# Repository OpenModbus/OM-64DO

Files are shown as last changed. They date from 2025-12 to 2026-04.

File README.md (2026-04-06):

# Open Modbus OM-64DO









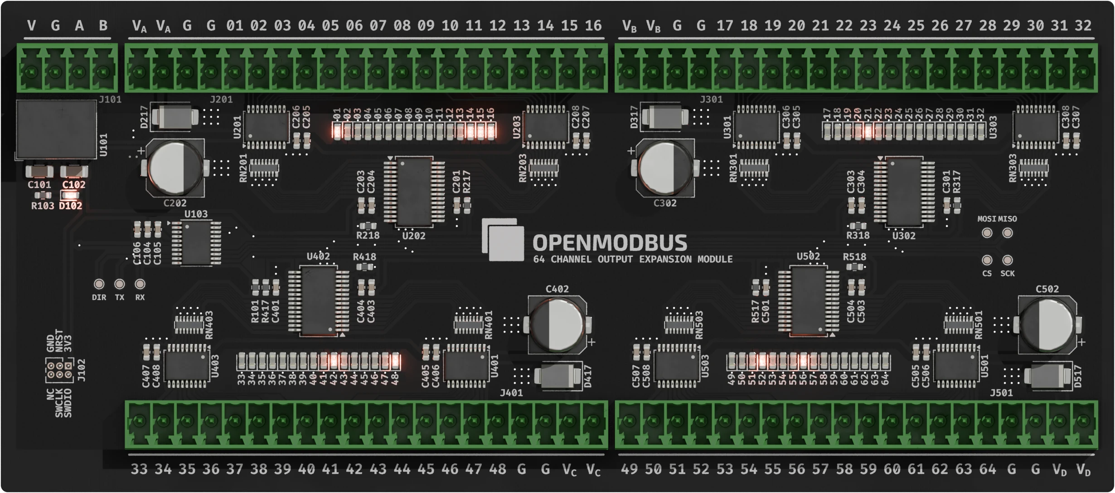
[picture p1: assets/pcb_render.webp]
PCB Render


A compact industrial-grade **64-channel Modbus RTU output module** featuring low-side drivers, per-channel LEDs, wide input voltage, DIN-rail support, and full configuration via Modbus holding registers. Designed for automation, distributed I/O, and custom control applications.

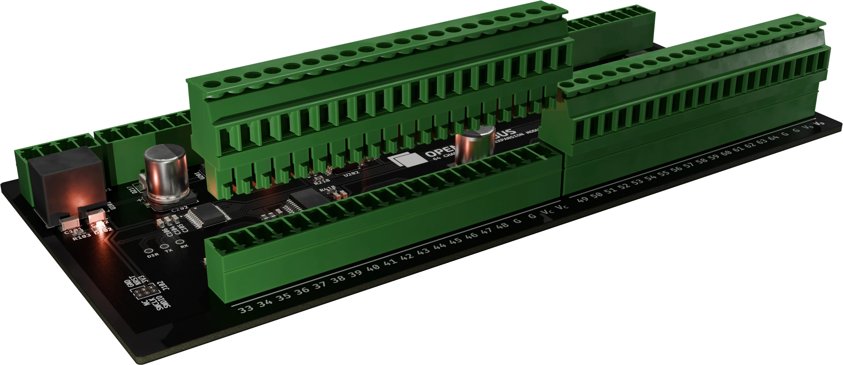
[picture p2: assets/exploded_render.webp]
Exploded PCB Render


## 1. Product Overview

The **Open Modbus OM-64DO** is a 64-channel low-side output expansion module intended for industrial automation, machine control, and distributed I/O networks using **Modbus RTU** over RS-485.  
It switches DC loads such as solenoids, relays, indicator lamps, locks, and alarms up to **48 VDC**.

The module combines an **STM32G031** microcontroller, four **MCP23S17 SPI expanders**, and eight **TBD62083 Darlington driver arrays**.  
This architecture enables reliable, flexible, and scalable output control with built-in protection and per-channel LED indication.

### 📦 Hardware Files

The full schematic and BOM are available at:

- Schematic → [https://github.com/OpenModbus/OM-64DO/blob/main/assets/schematics.pdf](https://github.com/OpenModbus/OM-64DO/blob/main/assets/schematics.pdf)
- BOM → [https://github.com/OpenModbus/OM-64DO/blob/main/assets/bom.csv](https://github.com/OpenModbus/OM-64DO/blob/main/assets/bom.csv)

Check the latest release for more!

## 2. Key Features

- 64 open-collector low-side outputs  
- Up to **500 mA per output**, **2 A max** per driver package  
- **5–48 VDC** recommended load voltage (50 V absolute maximum)  
- Wide supply input: **7–28 VDC**  
- RS-485 Modbus RTU communication (THVD1450 transceiver)  
- Fully configurable serial parameters  
- Per-channel LED indicators  
- DEGSON 15EDG pluggable screw terminals
- DIN-rail mount using **UM72S profile**  
- Compact PCB (163 × 72 mm)

## 3. Applications

Ideal for:

- PLC expansion  
- Building automation  
- Access control  
- Alarm and signaling systems  
- Relay switching  
- Industrial prototyping  

## 4. Hardware Architecture

### Microcontroller  

The STM32G031F8P6 MCU handles Modbus RTU processing, configuration storage, SPI communication, and output refresh logic.

### I/O Expanders  

Four MCP23S17 SPI-based expanders provide the 64 output control signals in groups of 16.

### Output Drivers  

The TBD62083 Darlington arrays switch the actual loads.  
Their key characteristics include:

- 8 channels per IC  
- 500 mA per channel  
- 2 A total per IC  
- Integrated flyback diodes  
- LED indication per channel  

### RS-485 Communication  

A robust THVD1450 transceiver provides differential RS-485 communication with:

- Fail-safe features  
- High ESD immunity  
- Suitable for long cable runs  

### Power  

The board accepts **7–28 VDC** and includes a high-efficiency **R-78E3.3-0.5** regulator for its 3.3 V logic domain.

## 5. Electrical Specifications

### Supply  

- **7–28 VDC** input  
- Internal regulated **3.3 V logic**  
- Low power MCU operation  

### Outputs  

- 64 open-collector low-side channels  
- 5–48 VDC recommended load  
- 50 VDC absolute maximum  
- 500 mA max per output  
- 2 A max per driver IC  
- Built-in flyback protection  
- LED indicator on each output  

### Communication  

- RS-485, 2-wire  
- Modbus RTU protocol  
- Default settings: **9600 baud, 8N1, address 1**  
- All communication parameters can be reconfigured via holding registers  

## 6. Mechanical Information

- PCB: **163 × 72 mm**  
- DIN-rail enclosure compatibility: **UM72S profile**  
- DEGSON 15EDG pluggable screw terminals  
- Mounting suitable for industrial control cabinets  

## 7. Functional Overview

Each output activates when its Modbus coil value is **1**, causing the driver to sink current to ground.  
When the coil value is **0**, the channel turns off, leaving the load unpowered.

A dedicated LED mirrors the state of each output channel.

## 8. Modbus Interface

### Supported Function Codes

- *0x01* — Read Coils  
- *0x05* — Write Single Coil  
- *0x0F* — Write Multiple Coils  
- *0x03* — Read Holding Registers  
- *0x06* — Write Single Register  
- *0x10* — Write Multiple Registers  

### Coils (Outputs 1–64)

Coils map directly to output channels.  
Addressing begins at **0x00**.

| Coil Address (Hex) | Function |
|---|---|
| 0  (**0x00**) | OUTPUT 1 |
| 1  (**0x01**) | OUTPUT 2 |
| 2  (**0x02**) | OUTPUT 3 |
| 3  (**0x03**) | OUTPUT 4 |
| 4  (**0x04**) | OUTPUT 5 |
| … | … |
| 63 (**0x3F**) | OUTPUT 64 |

### Holding Registers

Configuration registers start at **0x00** and are stored in non-volatile memory.

| Register Address (Hex) | Name | Description | Allowed Values | Default |
|---|---|---|---|---|
| 0 (**0x00**) | Slave Address  | Modbus device ID | 1–247 | 1 |
| 1 (**0x01**) | Baud Rate Code | Serial speed selector: **0=1200**, **1=2400**, **2=4800**, **3=9600**, **4=19200**, **5=38400**, **6=57600**, **7=115200**, **8=230400**, **9=460800**, **10=921600** | 0–10 | 3 |
| 2 (**0x02**) | Parity | Communication parity | 0=None, 1=Even, 2=Odd | 0 |
| 3 (**0x03**) | Data Bits | Serial data width | 5–9 (typ. 8) | 8 |
| 4 (**0x04**) | Stop Bits | Serial stop bits | 1–2 | 1 |

### Example Modbus Commands

Below are typical Modbus RTU frames for controlling and configuring the OM-64DO.

#### Turn ON Output 1  

Function: Write Single Coil (0x05)  
Coil address: `0x0000`  
Value: ON → `0xFF00`  
**Frame:** `01 05 00 00 FF 00 8C 3A`

#### Turn ON Outputs 5–12  

Function: Write Multiple Coils (0x0F)  
Start address: `0x0004`  
Quantity: `0x0008` (8 coils)  
Data: `FF` (all eight bits ON)  
**Frame:** `01 0F 00 04 00 08 01 FF 4F 15`

#### Turn ON All Outputs (1–64)

Function: Write Multiple Coils (0x0F)  
Start address: `0x0000`  
Quantity: `0x0040` (64 coils)  
Data: `FF FF FF FF FF FF FF FF`  
**Frame:** `01 0F 00 00 00 40 08 FF FF FF FF FF FF FF FF AA 20`

#### Turn OFF All Outputs

Function: Write Multiple Coils (0x0F)  
Start address: `0x0000`  
Quantity: `0x0040`  
Data: `00 00 00 00 00 00 00 00`  
**Frame:** `01 0F 00 00 00 40 08 00 00 00 00 00 00 00 00 EB A4`

#### Read All Outputs

Function: Read Coils (0x01)  
Start address: `0x0000`  
Quantity: `0x0040`  
**Frame:** `01 01 00 00 00 40 3D FA`

#### Set Device Address

Function: Write Single Register (0x06)  
Register: `0x0000` (Slave Address)  
Value: `0x0005`  
**Frame:** `01 06 00 00 00 05 49 C9`

#### Set Baud Rate

Function: Write Single Register (0x06)  
Register: `0x0001` (Baud Rate Code)  
Value: `0x0007` → 115200 baud  
**Frame:** `01 06 00 01 00 07 99 C8`

## 9. Wiring  

The **OM-64DO** uses low-side (open-collector) switching.
That means the module connects the load to ground when ON, and the load must be powered from your external power supply.

The 64 outputs are grouped into four banks of 16 (Bank A–D).
This allows one board to drive devices powered from different voltages simultaneously.

**Examples**:

- Bank A → 12 V devices
- Bank B → 24 V relays
- Bank C → 48 V solenoids
- Bank D → 5 V indicators

### Low-Side Output Principle

Each output contains a protected Darlington transistor that sinks current:

```text
Load +V  ─────── Load ─────── OUTx (SINK)
                                    │
                                    └── GND (OM-64DO)
```

### Recommended Wiring Steps

- Connect the load voltage (5–48 VDC) to the Vx terminal of the bank.
- Connect the output pin (OUTx) to the negative side of the load.
- Tie power supply GND to OM-64DO GND.
- Ensure the supply can support the total current of that bank.

**⚠️ Important Grounding Requirement**:
All load power supplies must share **a common ground** with the OM-64DO.
This is required for the low-side drivers and internal logic to reference the same electrical 0 V.

### Wiring Example

The example below shows how to drive 24 V and 12 V relays at the same time using separate banks.

- Bank A (VA) → 24 V relays
- Bank B (VB) → 12 V relays
- Both supplies share a common ground
- Loads return their negative side to the selected OUTx channel

<picture>
  <source media="(prefers-color-scheme: dark)" srcset="./assets/wiring_example_dark.png">
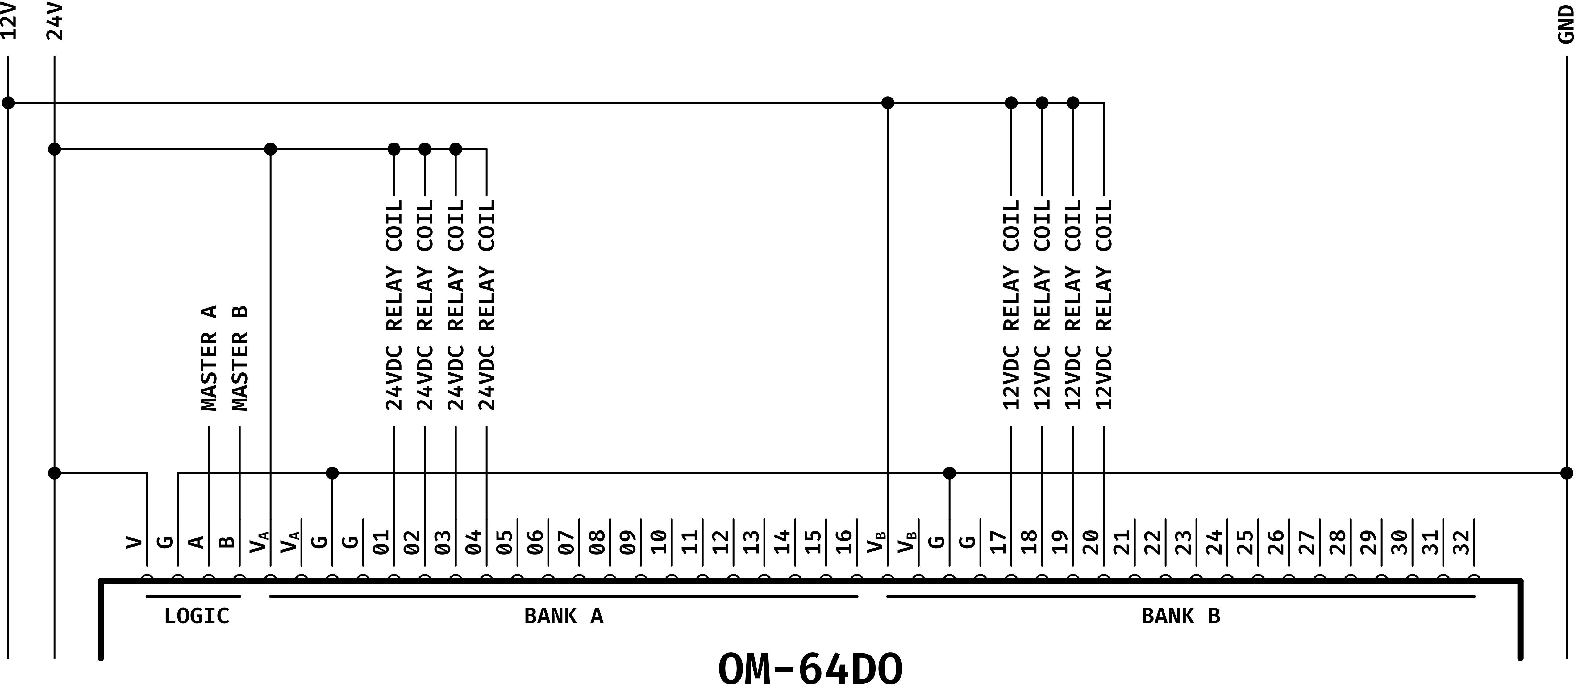
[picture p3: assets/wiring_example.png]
Wiring example
  
</picture>

This wiring approach can be extended to all four banks, each with its own voltage.

## 10. Safety Notes

- Do not exceed **50 VDC** load voltage  
- Ensure load currents stay within limits  
- For inductive loads, external suppression can further improve reliability  
- Maintain proper RS-485 termination and shielding  

## 11. Contact & Support  

For questions, feedback, or technical assistance regarding the Open Modbus OM-64DO, the following support channels are available:

### 📧 Email Support

For general inquiries, firmware questions, or troubleshooting:
[contact@sszczep.dev](mailto:contact@sszczep.dev)

### 🛠 GitHub Repository

Issue tracker, source code, hardware design files, and community contributions:
[https://github.com/OpenModbus/OM-64DO](https://github.com/OpenModbus/OM-64DO)

### 💬 Open Modbus Discussions

Share projects, ask for help, or suggest features:
[https://github.com/orgs/OpenModbus/discussions](https://github.com/orgs/OpenModbus/discussions)

### 📝 Bug Reports & Feature Requests

Submit issues directly via GitHub Issues:
[https://github.com/OpenModbus/OM-64DO/issues](https://github.com/OpenModbus/OM-64DO/issues)

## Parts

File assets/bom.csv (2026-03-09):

Reference | Value | Datasheet | Opis | Qty | # | Manufacturer | Part Number | Mouser# | LCSC#
U202,U302,U402,U502 | MCP23S17T-E/SS | http://ww1.microchip.com/downloads/en/DeviceDoc/20001952C.pdf | 16-bit I/O expander, SPI, interrupts, w pull-ups, SSOP-28 | 4 | 1 | Microchip | MCP23S17T-E/SS | 579-MCP23S17T-E/SS | C128577
U101 | R-78E3.3-0.5 | https://recom-power.com/pdf/Innoline/R-78E-0.5.pdf | 0.5A Step-Down DC/DC-Regulator, 6-28V input, 3.3V fixed Output Voltage, LM78xx replacement, -40°C to +85°C, SIP3 | 1 | 2 | RECOM | R-78E3.3-0.5 | 919-R-78E3.3-0.5 | C18212316
U201,U203,U301,U303,U401,U403,U501,U503 | TBD62083AFNG | https://toshiba.semicon-storage.com/info/datasheet_en_20160511.pdf?did=29893 | Gate Drivers DMOS Transistor Array 8-CH, 50V/0.5A | 8 | 3 | Toshiba | TBD62083AFNG,EL | 757-TBD62083AFNGEL | C163229
F101 | 0.5A | https://www.littelfuse.com/assetdocs/littelfuse_fuse_466_datasheet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 | Fuse, small symbol | 1 | 4 | Littelfuse | 0466.500NR | 576-0466.500NR | C151133
D217,D317,D417,D517 | SMBJ45A | https://www.littelfuse.com/assetdocs/tvs-diodes-smbj-series-datasheet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 | ESD Protection Diodes / TVS Diodes TVS 500W 50V | 4 | 5 | Littelfuse | SMBJ45A | 576-SMBJ45A | C720171
D104 | SMAJ28A | https://www.littelfuse.com/media?itemid=75e32973-b177-4ee3-a0ff-cedaf1abdb93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 | 400W unidirectional Transient Voltage Suppressor, 28.0Vr, SMA(DO-214AC) | 1 | 6 | Littelfuse | SMAJ28A | 576-SMAJ28A | C148227
D101 | SM712-02HTG | https://www.littelfuse.com/~/media/electronics/datasheets/tvs_diode_arrays/littelfuse_tvs_diode_array_sm712_datasheet.pdf.pdf | 7V/12V, 600W Asymmetrical TVS Diode Array, SOT-23 | 1 | 7 | Littelfuse | SM712-02HTG | 576-SM712-02HTG | C172881
D103 | CD123D-B140LR | https://www.mouser.com/catalog/specsheets/bourns_CD123D-B1xR.pdf | Schottky diode, small symbol | 1 | 8 | Bourns | CD123D-B140LR | 652-CD123D-B140LR | C6877135
U103 | STM32G031F8P6 | https://www.st.com/resource/en/datasheet/stm32g031f8.pdf | STMicroelectronics Arm Cortex-M0+ MCU, 64KB flash, 8KB RAM, 64 MHz, 1.7-3.6V, 18 GPIO, TSSOP20 | 1 | 9 | STMicroelectronics | STM32G031F8P6 | 511-STM32G031F8P6 | C529334
U102 | THVD1450DRBR | https://www.ti.com/lit/ds/symlink/thvd1450.pdf | 3.3-V to 5-V RS-485 transceiver with ±18-kV IEC ESD protection, VSON-8 | 1 | 10 | Texas Instruments | THVD1450DRBR | 595-THVD1450DRBR | C1850226
C101,C102 | 10u | ~ | 10 uF 50 VDC 10% 1206 X5R AEC-Q200 | 2 | 11 | Murata | GRT31CR61H106KE01L | 81-GRT31CR61H106KE1L | C417124
C103,C105,C106,C201,C204,C206,C208,C301,C304,C306,C308,C401,C404,C406,C408,C501,C504,C506,C508 | 0.1u | ~ | 0.1 uF 50 VDC 10% 0603 X7R AEC-Q200 | 19 | 12 | Murata | GCJ188R71H104KA12D | 81-GCJ188R71H104KA2D | C161115
C104,C203,C303,C403,C503 | 2.2u | ~ | 2.2 uF 50 VDC 10% 0603 X5R AEC-Q200 | 5 | 13 | Murata | GRT188R61H225KE13D | 81-GRT188R61H225KE3D | C668370
C202,C302,C402,C502 | 100u | ~ | Aluminum Electrolytic Capacitors - SMD 100UF 63V 20% | 4 | 14 | Nichicon | UCM1J101MNL1GS | 647-UCM1J101MNL1GS | C445456
C205,C207,C305,C307,C405,C407,C505,C507 | 1u | ~ | 1 uF 50 VDC 10% 0603 X5R AEC-Q200 | 8 | 15 | Murata | GRT188R61H105KE13D | 81-GRT188R61H105KE3D | C126631
D102,D201,D202,D203,D204,D205,D206,D207,D208,D209,D210,D211,D212,D213,D214,D215,D216,D301,D302,D303,D304,D305,D306,D307,D308,D309,D310,D311,D312,D313,D314,D315,D316,D401,D402,D403,D404,D405,D406,D407,D408,D409,D410,D411,D412,D413,D414,D415,D416,D501,D502,D503,D504,D505,D506,D507,D508,D509,D510,D511,D512,D513,D514,D515,D516 | RED | ~ | Single Color LEDs Red Clear 621nm | 65 | 16 | LITEON | LTST-C190EKT | 859-LTST-C190EKT | C364560
J101 | 15EDGVC-3.5-4P | ~ | Generic connector, single row, 01x04, script generated (kicad-library-utils/schlib/autogen/connector/) | 1 | 17 | DEGSON | 10030000681 |  | C22380434
J102 | 02x03 1.27 | ~ | Generic connector, double row, 02x03, odd/even pin numbering scheme (row 1 odd numbers, row 2 even numbers), script generated (kicad-library-utils/schlib/autogen/connector/) | 1 | 18
J201,J301,J401,J501 | 15EDGVC-3.5-20P | ~ | Fixed Terminal Blocks | 4 | 19 | DEGSON | 10030000695 |  | C5188336
R101,R102,R217,R317,R417,R517 | 10K | ~ | SMD 0603 10KOhm 1% 1/8W AEC-Q200 | 6 | 20 | Panasonic | ERJ-H3EF1002V | 667-ERJ-H3EF1002V | C4297913
R103 | 470 | ~ | SMD 0603 470Ohm 5% 1/4W AEC-Q200 | 1 | 21 | Panasonic | ERJ-UP3J471V | 667-ERJ-UP3J471V | C491199
R201,R202,R203,R204,R205,R206,R207,R208,R209,R210,R211,R212,R213,R214,R215,R216,R301,R302,R303,R304,R305,R306,R307,R308,R309,R310,R311,R312,R313,R314,R315,R316,R401,R402,R403,R404,R405,R406,R407,R408,R409,R410,R411,R412,R413,R414,R415,R416,R501,R502,R503,R504,R505,R506,R507,R508,R509,R510,R511,R512,R513,R514,R515,R516 | 3K3 | ~ | SMD 0603 3K3Ohm 5% 1/4W AEC-Q200 | 64 | 22 | Panasonic | ERJ-UP3J332V | 667-ERJ-UP3J332V | C491202
R218,R318,R418,R518 | 33 | ~ | SMD 0603 33Ohm 1% 1/8W AEC-Q200 | 4 | 23 | Panasonic | ERJ-H3EF33R0V | 667-ERJ-H3EF33R0V | C4313361
RN201,RN203,RN301,RN303,RN401,RN403,RN501,RN503 | 47R | ~ | Resistor Array Convex 8x0602 47Ohm 5% AEC-Q200 | 8 | 24 | Panasonic | EXB-2HV470JV | 667-EXB-2HV470JV | C713462
RN202,RN204,RN302,RN304,RN402,RN404,RN502,RN504 | 100K | ~ | Resistor Array Convex 8x0602 100KOhm 5% AEC-Q200 | 8 | 25 | Panasonic | EXB-2HV104JV | 667-EXB-2HV104JV | C713455

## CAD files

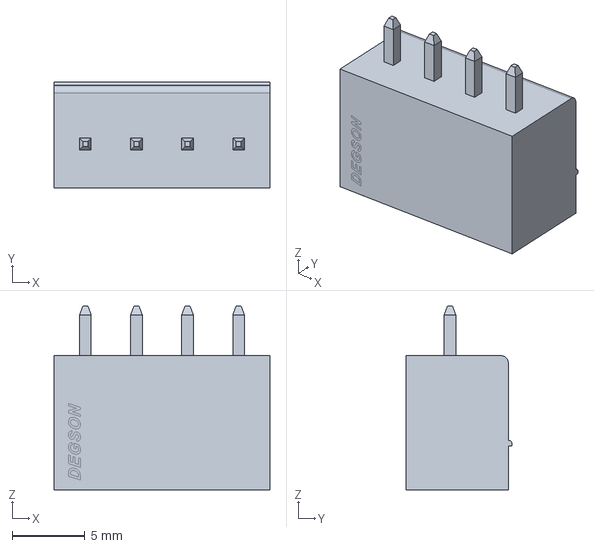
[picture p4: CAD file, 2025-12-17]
kicad/Project_Models/15EDGVC-3.5-04P-14-00A&Z(H).stp
14.8 x 7.24 x 12.6 mm

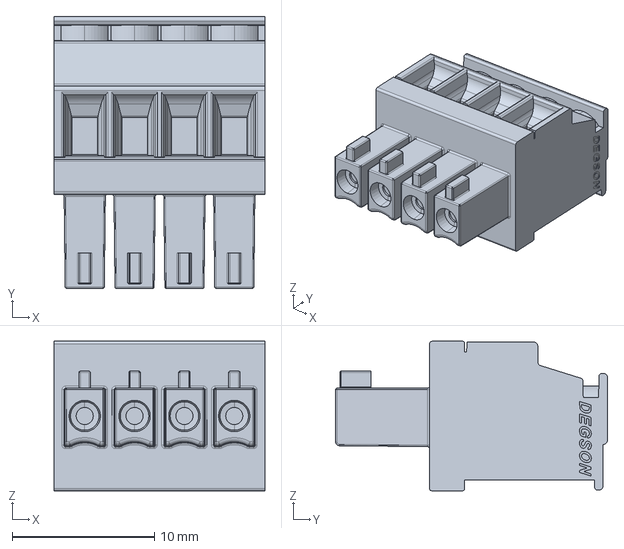
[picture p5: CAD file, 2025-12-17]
kicad/Project_Models/15EDGKA-3.5-04P-1Y-100A&Z(H).stp
14.8 x 19.1 x 10.5 mm

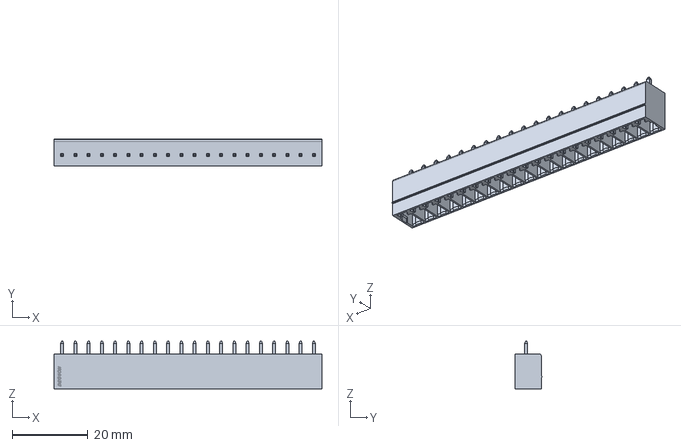
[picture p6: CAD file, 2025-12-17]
kicad/Project_Models/15EDGVC-3.5-20P-14-00A&Z(H).stp
70.8 x 7.24 x 12.6 mm

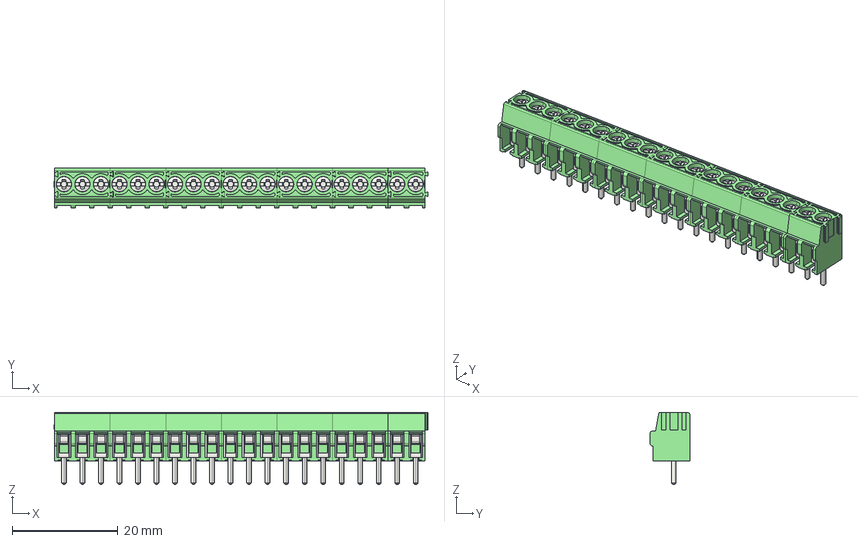
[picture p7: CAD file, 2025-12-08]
kicad/Project_Models/pxc_1709678_03_01_PT-1-5-20-3-5-H_3D.stp
70.7 x 7.55 x 13.6 mm
LP_PT_1_5_klh_3_5_horizontal x 18
AC_PT_1_5_PVH_H0_Schraube x 18
AT_PT_1_5_3_50_H x 7
LP_PT_1_5_klh_3_5_horizontal.1 x 2
AC_PT_1_5_PVH_H0_Schraube.1 x 2

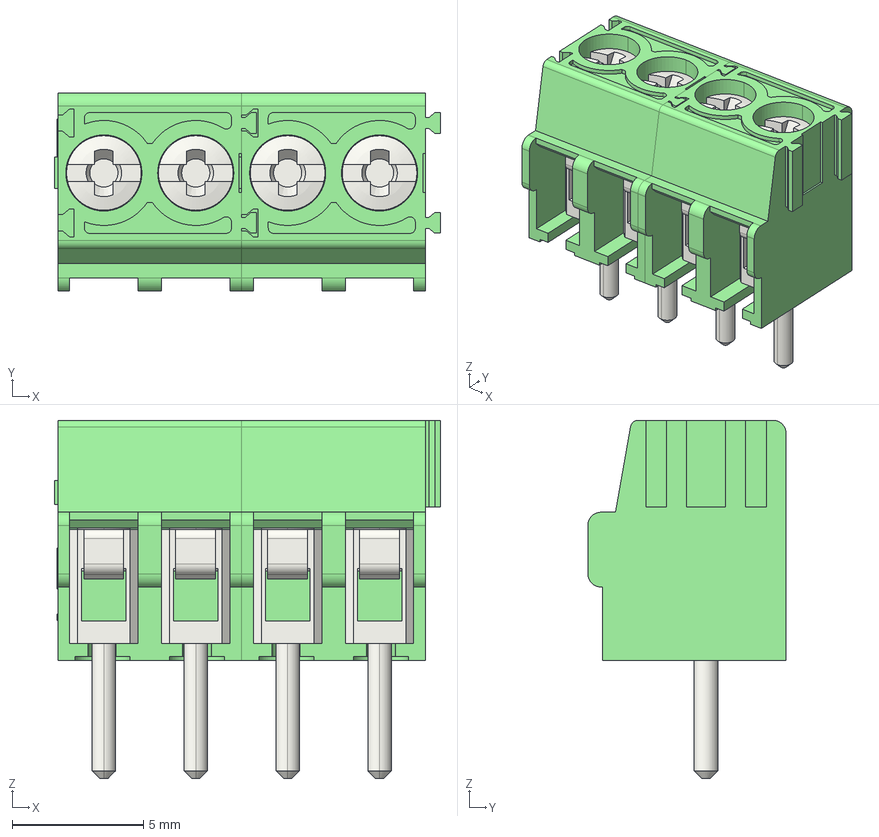
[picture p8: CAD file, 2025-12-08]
kicad/Project_Models/pxc_1984633_03_00_PT-1-5-4-3-5-H_3D.stp
14.7 x 7.55 x 13.6 mm
LP_PT_1_5_klh_3_5_horizontal x 4
AC_PT_1_5_PVH_H0_Schraube x 4
AT_PT_1_5_3_50_H x 2

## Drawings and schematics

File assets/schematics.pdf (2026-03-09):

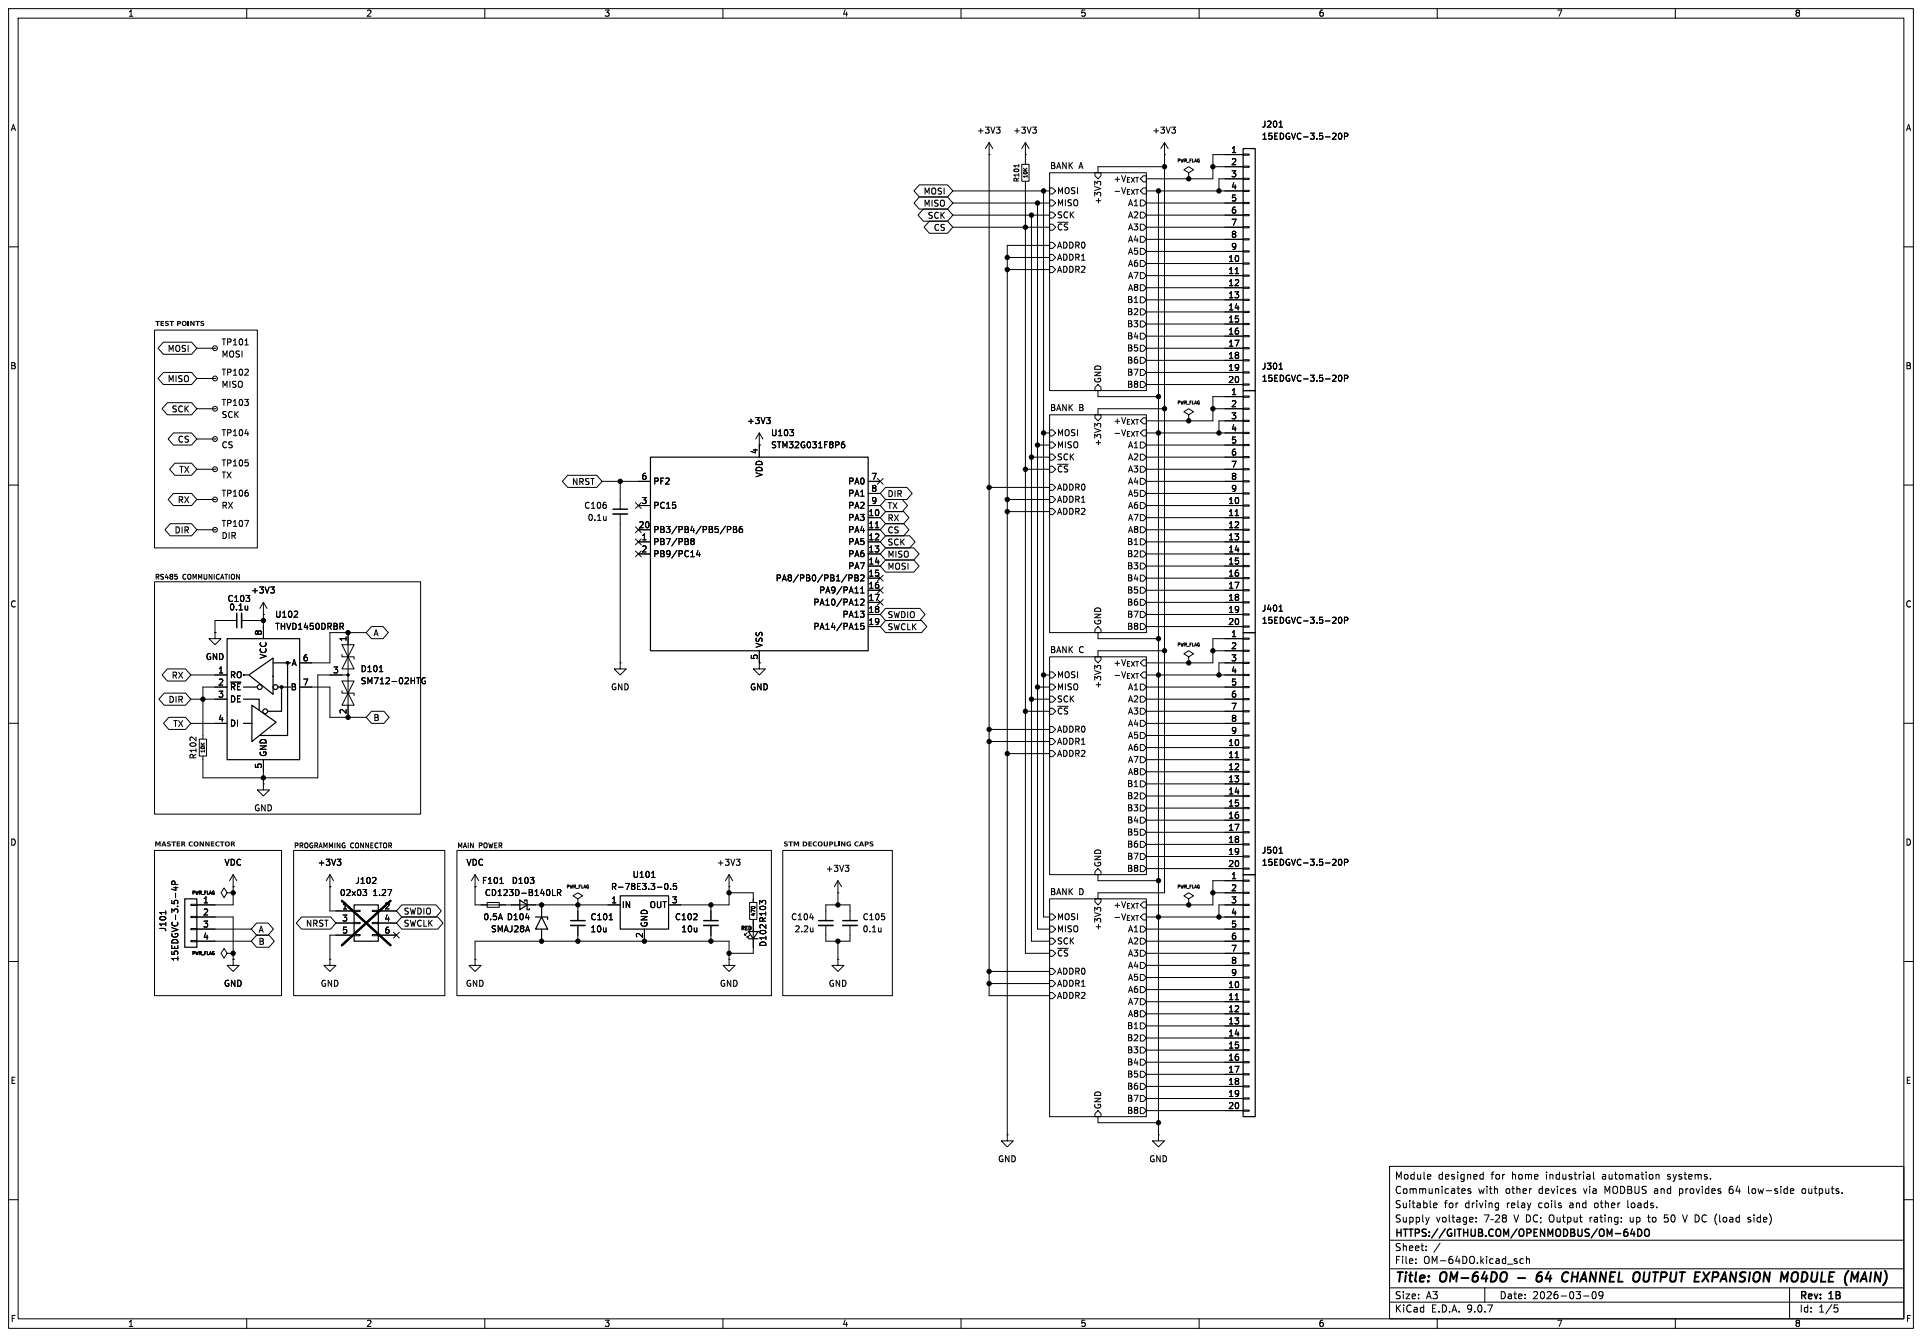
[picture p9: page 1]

TP101 MOSI TP102 MISO
TX MOSI SCK MISO
+3V3 TP104 CSC103

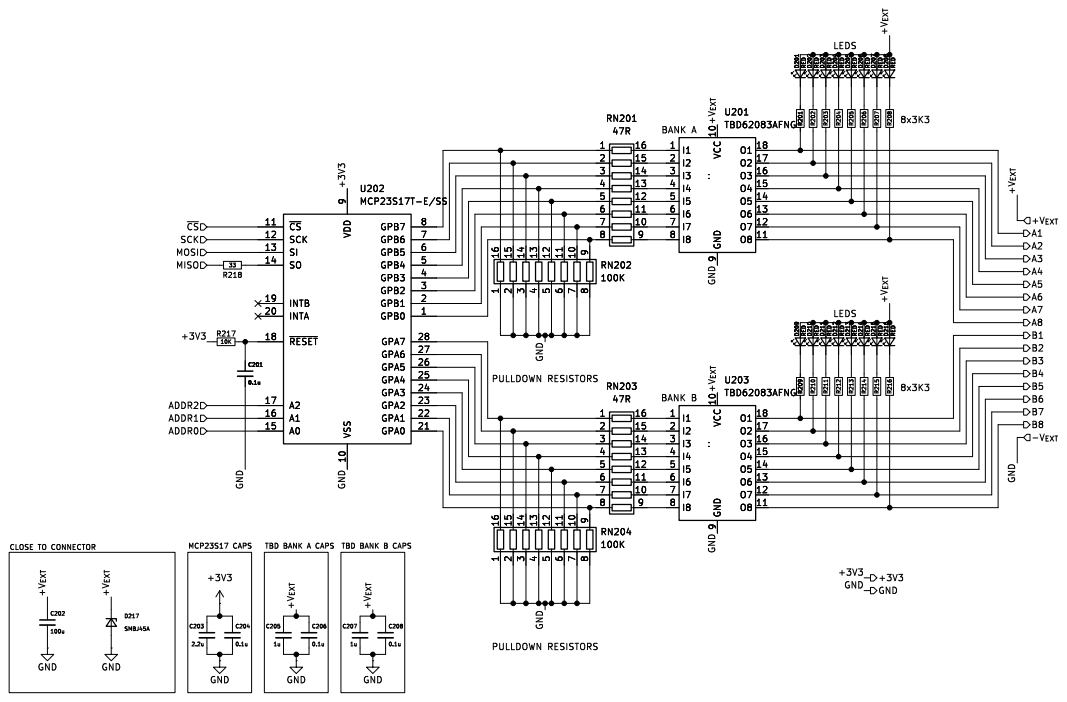
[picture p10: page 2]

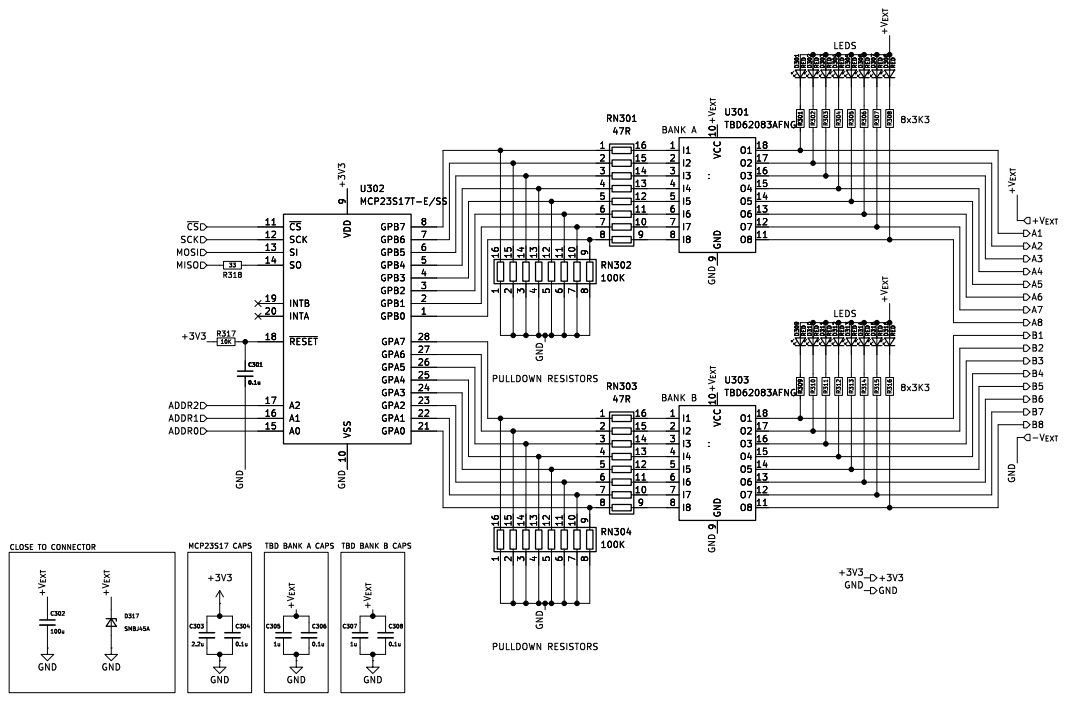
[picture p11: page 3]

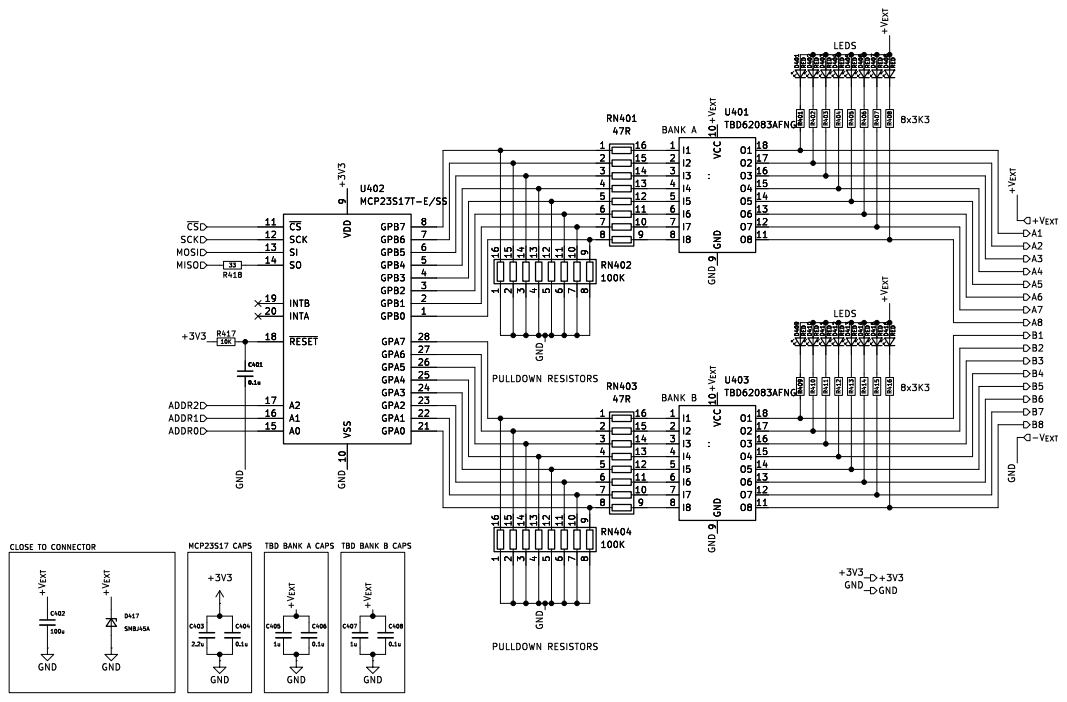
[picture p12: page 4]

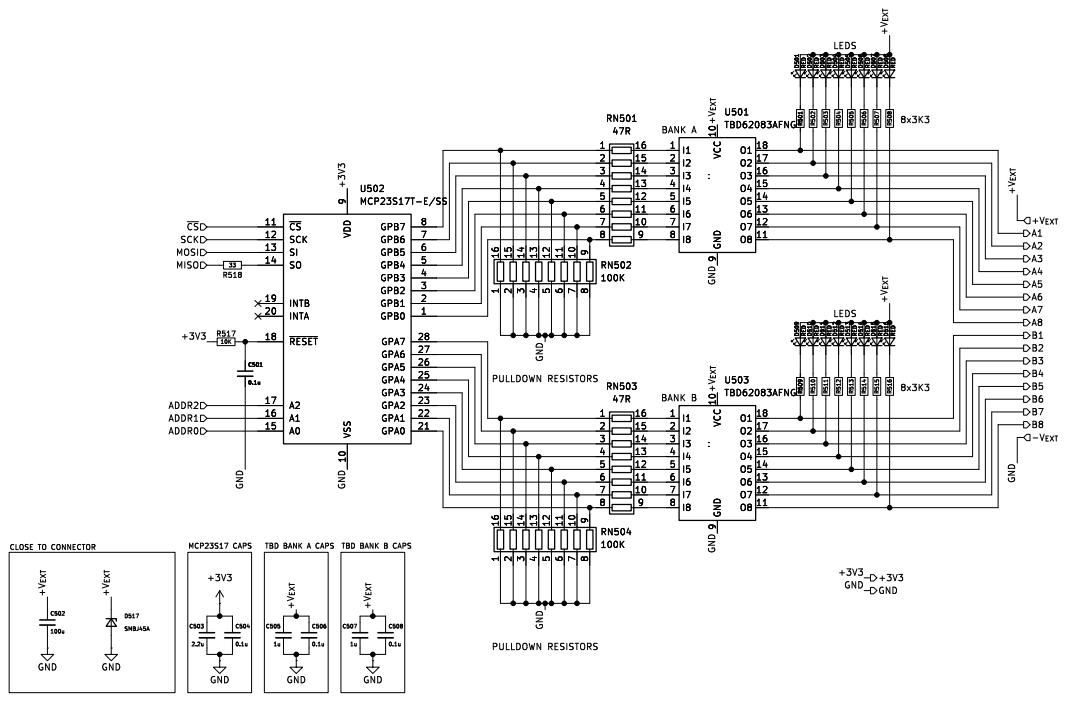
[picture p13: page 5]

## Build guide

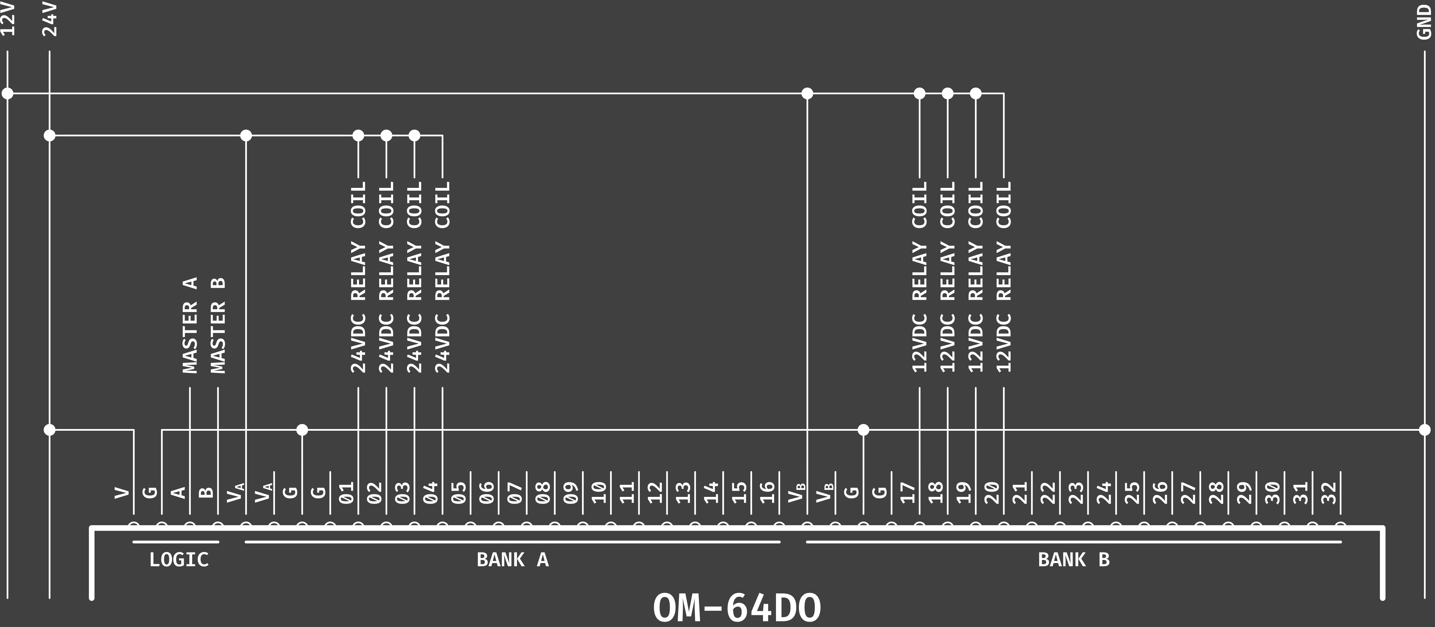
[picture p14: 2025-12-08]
assets/wiring_example_dark.png

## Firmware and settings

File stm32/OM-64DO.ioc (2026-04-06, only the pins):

Mcu.UserName=STM32G031F8Px
PA1.GPIO_Label=USART2_DIR
PA1.Signal=GPIO_Output
PA2.Signal=USART2_TX
PA3.Signal=USART2_RX
PA4.GPIO_Label=SPI1_CS
PA4.Signal=GPIO_Output
PA5.Signal=SPI1_SCK
PA6.Signal=SPI1_MISO
PA7.Signal=SPI1_MOSI

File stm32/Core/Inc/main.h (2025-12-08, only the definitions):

#define USART2_DIR_Pin GPIO_PIN_1
#define USART2_DIR_GPIO_Port GPIOA
#define SPI1_CS_Pin GPIO_PIN_4
#define SPI1_CS_GPIO_Port GPIOA

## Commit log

2025-12-08 feat: first OM-64DO release
    [OM-64DO-B_Cu.gbr, OM-64DO-B_Mask.gbr, OM-64DO-B_Paste.gbr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]
2025-12-08 feat: add power indicator, add STM32 code
    [OM-64DO-B_Cu.gbr, OM-64DO-B_Mask.gbr, OM-64DO-B_Paste.gbr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]
2025-12-08 feat: add note about PCBWay contest
2025-12-09 feat: update resistor array footprint, change power trace thickness, optimize design
    [OM-64DO-B_Cu.gbr, OM-64DO-B_Mask.gbr, OM-64DO-B_Paste.gbr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]
2025-12-17 feat: add pluggable connector, add JLCPCB production files, improve routing
    [15EDGKA-3.5-04P-1Y-100A&Z(H).stp, 15EDGVC-3.5-04P-14-00A&Z(H).stp, 15EDGVC-3.5-20P-14-00A&Z(H).stp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]
2025-12-18 fix: wrong silkscreen placement, missing GND <> -V_coil tie
    [OM-64DO-B_Cu.gbl, OM-64DO-B_Cu.gbr, OM-64DO-B_Mask.gbr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]
2026-03-09 feat: add extra power rail protection
    [OM-64DO.kicad_sch, logic_block.kicad_sch]
2026-03-09 feat: embed pcbnew font
2026-03-09 feat: update schematics board rev
    [OM-64DO.kicad_sch, logic_block.kicad_sch]
2026-03-09 feat: add LCSC parts numbers
    [OM-64DO.kicad_sch, logic_block.kicad_sch]
2026-03-09 feat: add kibot
    [bom.csv]
2026-03-09 feat: remove artifacts from source code
    [OM-64DO-B_Cu.gbl, OM-64DO-B_Cu.gbr, OM-64DO-B_Mask.gbr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]
2026-03-09 feat: change board artifact name
2026-03-09 feat: change silkscreen text position
2026-03-12 feat: reduce board size, update pcb design
    [OM-64DO.kicad_sch, logic_block.kicad_sch]
2026-04-06 feat: add stm32 code

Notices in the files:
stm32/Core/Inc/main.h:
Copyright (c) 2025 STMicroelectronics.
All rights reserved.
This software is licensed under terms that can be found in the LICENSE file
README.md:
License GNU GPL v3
